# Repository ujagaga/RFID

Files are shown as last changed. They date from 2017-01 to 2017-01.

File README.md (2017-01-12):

RFID reader project for AtTiny2313 using MIFARE RFID-RC522 spi module

The RFID library is based on Addicore arduino library. I re-wrote it as pure C library and removed 
everything not esential to bare reading of an RFID TAG id to reduce the code size.

The initial commit contains a basic example of reading a tag and outputting the 4 bytes of id to UART.
The latest commit contains:
- full RFID example which can record up to 32 tag ids and unlock an electromagnetic lock
- EEPROM reader device which can be used to record the RFID readers memory and write it back on command
so that re-distributing codes between multiple locks can be simpified
- Linux and Windows console applications for administrating tag ids using either the EEPROM copy device 
or the RFID reader directly.

more details will be in the doc folder.

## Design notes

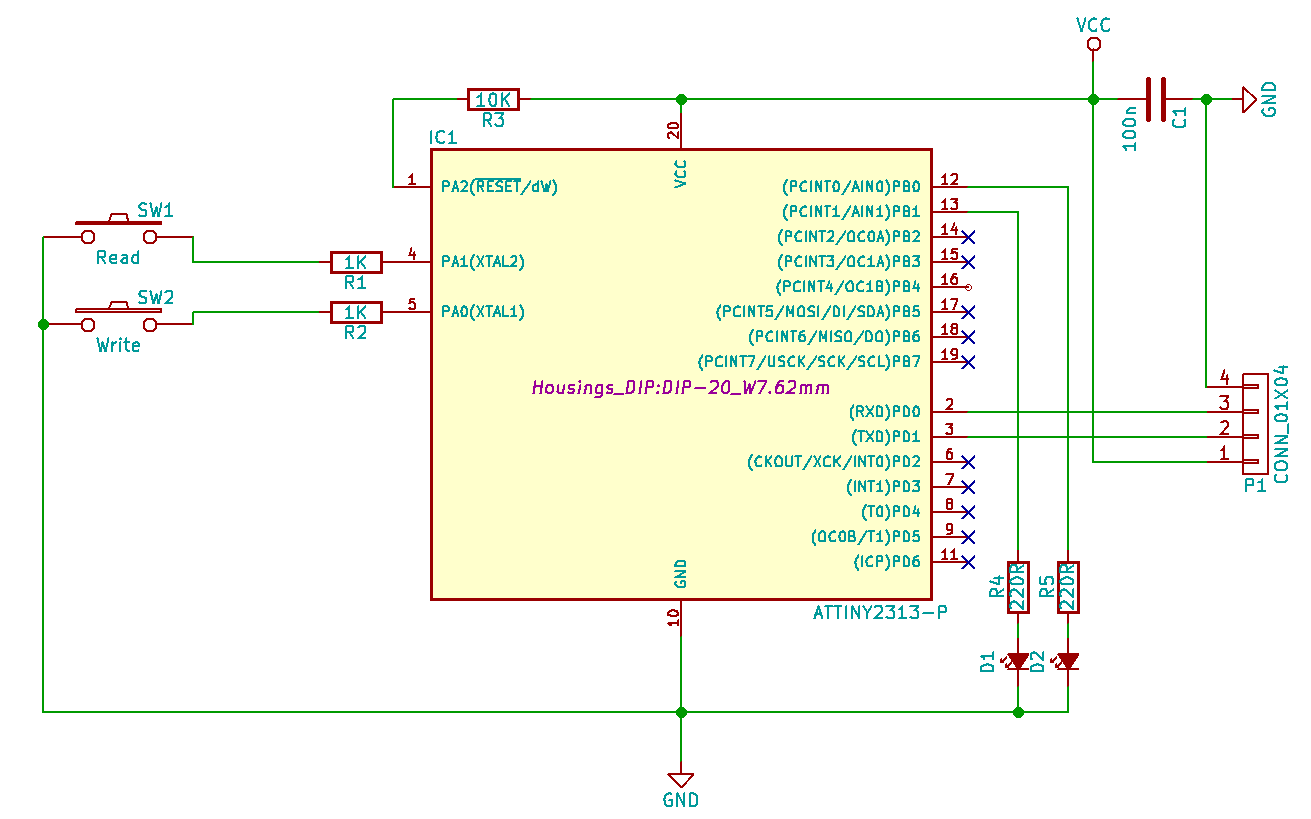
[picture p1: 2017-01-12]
doc/EEPROM_copy_device_schematic.png

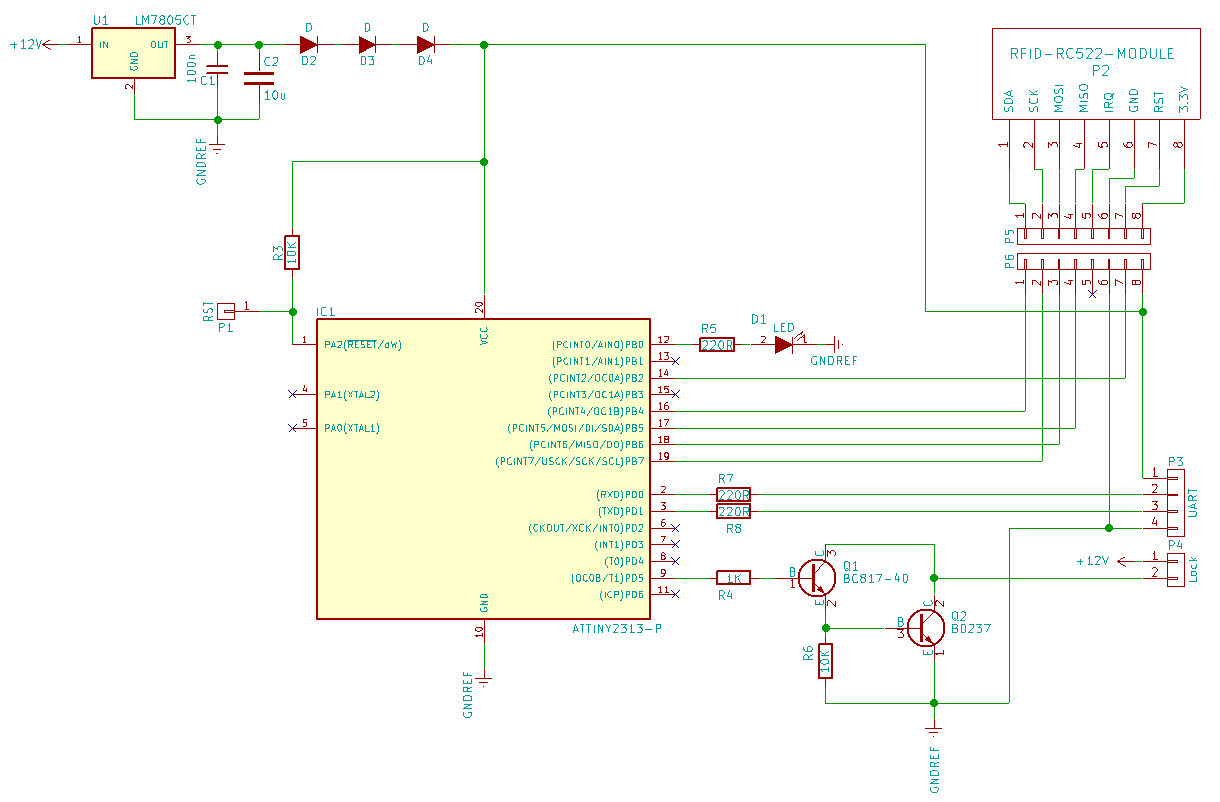
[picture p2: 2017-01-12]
doc/Reader_schematic.png

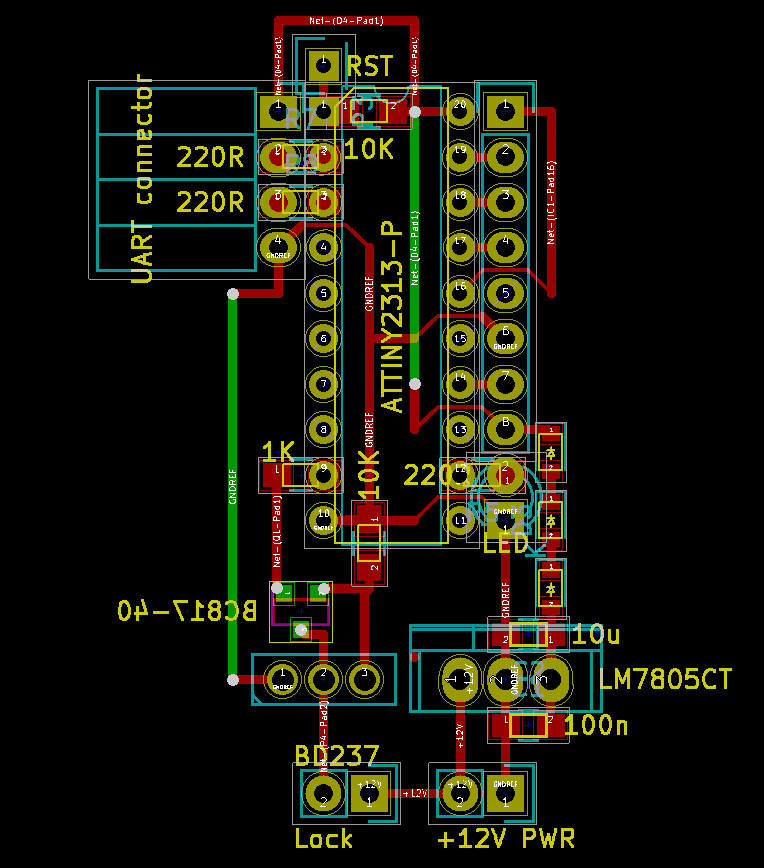
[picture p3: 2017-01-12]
Hardware/Reader_PCB.png

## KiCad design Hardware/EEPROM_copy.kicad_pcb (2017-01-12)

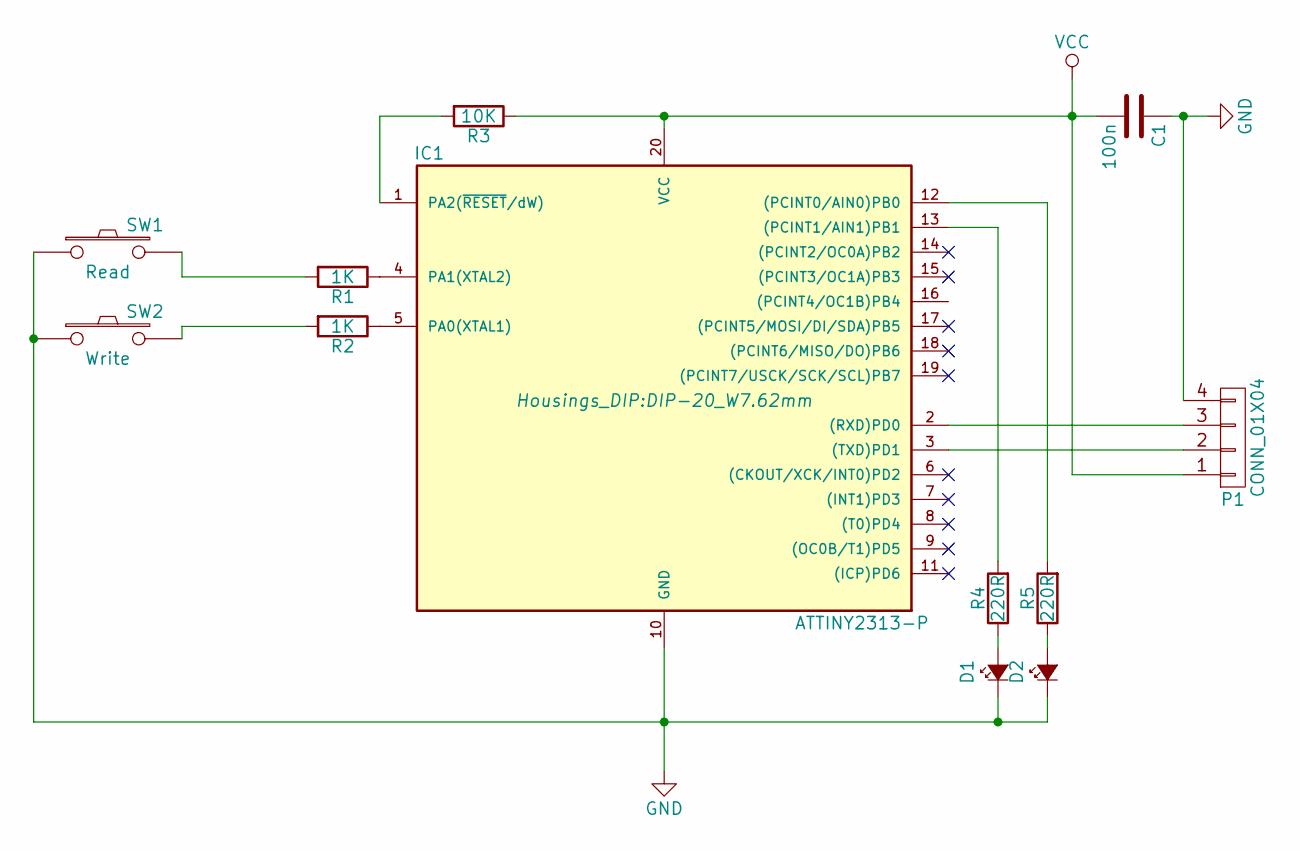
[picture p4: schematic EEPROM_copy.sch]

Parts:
C1: 100n; C_0805_HandSoldering
D1, D2: Led_Small; LED-3MM
IC1: ATTINY2313-P; DIP-20_W7.62mm
P1: CONN_01X04; Socket_Strip_Angled_1x04
R1, R2: 1K; R_0805
R3: 10K; R_0805
R4, R5: 220R; R_0805
SW1: Read; Micro_sw_1
SW2: Write; Micro_sw_1

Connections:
GND: C1.1, D1.1 (K), D2.1 (K), IC1.10 (GND), P1.4, SW1.1, SW2.1
unnamed: D1.2 (A), R4.1
unnamed: D2.2 (A), R5.1
unnamed: IC1.1 (PA2(~RESET~/dW)), R3.2
unnamed: IC1.2 ((RXD)PD0), P1.3
unnamed: IC1.3 ((TXD)PD1), P1.2
unnamed: IC1.4 (PA1(XTAL2)), R1.1
unnamed: IC1.5 (PA0(XTAL1)), R2.1
unnamed: IC1.12 ((PCINT0/AIN0)PB0), R5.2
unnamed: IC1.13 ((PCINT1/AIN1)PB1), R4.2
unnamed: R1.2, SW1.2
unnamed: R2.2, SW2.2
VCC: C1.2, IC1.20 (VCC), P1.1, R3.1

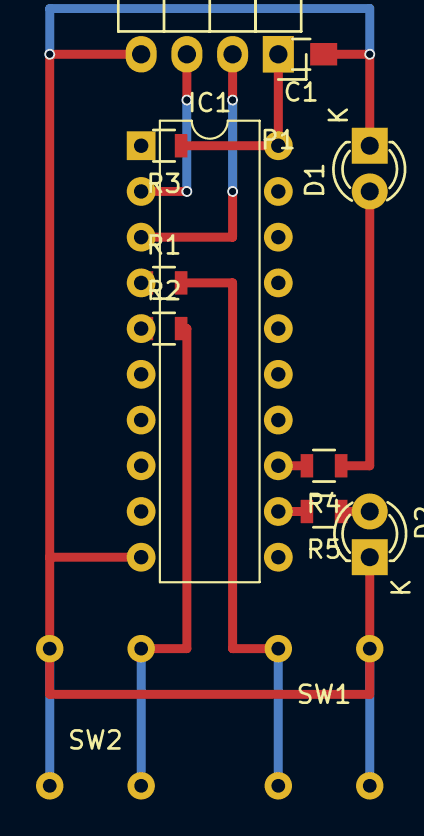
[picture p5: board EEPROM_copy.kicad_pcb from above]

Board: 2 copper layers, 12 parts (0 on the bottom side), 13 nets.

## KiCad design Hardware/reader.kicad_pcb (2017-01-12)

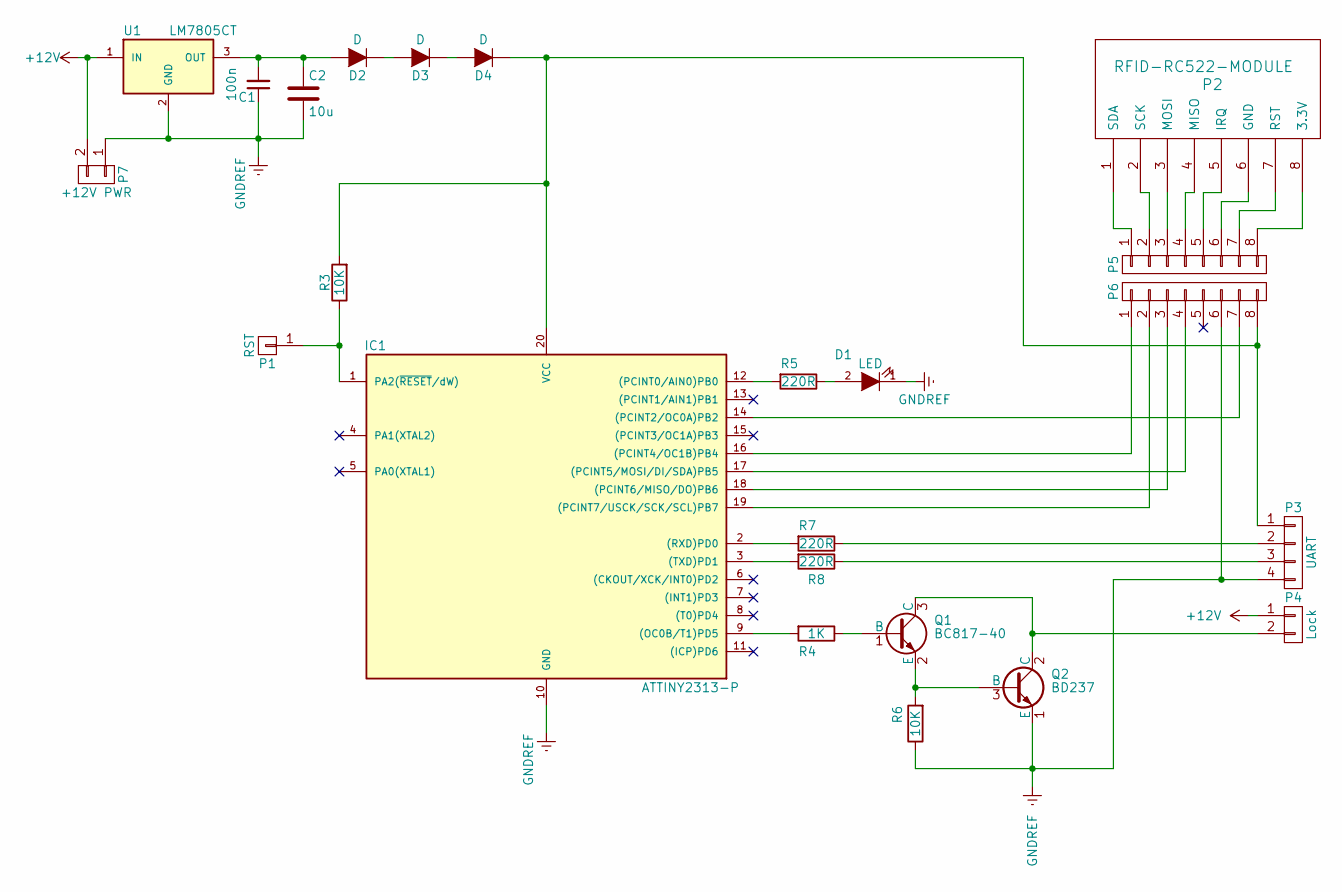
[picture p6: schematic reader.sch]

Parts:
C1: 100n; C_0805_HandSoldering
C2: 10u; C_0805_HandSoldering
D1: LED; LED-3MM
D2, D3, D4: D; D_0805
IC1: ATTINY2313-P; DIP-20_W7.62mm
P1: RST; Socket_Strip_Straight_1x01
P2: RFID-RC522-MODULE; Socket_Strip_Straight_1x08
P3: UART; Socket_Strip_Angled_1x04
P4: Lock; Socket_Strip_Straight_1x02
P5, P6: CONN_01X08; Socket_Strip_Straight_1x08
P7: +12V PWR; Socket_Strip_Straight_1x02
Q1: BC817-40; SOT-23
Q2: BD237; SOT126_SOT32_Housing_Vertical
R3, R6: 10K; R_0805_HandSoldering
R4: 1K; R_0805_HandSoldering
R5, R7, R8: 220R; R_0805_HandSoldering
U1: LM7805CT; TO-220

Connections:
+12V: P4.1, P7.2, U1.1 (IN)
GNDREF: C1.1, C2.2, D1.1 (K), IC1.10 (GND), P3.4, P6.6, P7.1, Q2.1 (E), R6.1, U1.2 (GND)
unnamed: C1.2, C2.1, D2.2 (A), U1.3 (OUT)
unnamed: D1.2 (A), R5.1
unnamed: D2.1 (K), D3.2 (A)
unnamed: D3.1 (K), D4.2 (A)
unnamed: D4.1 (K), IC1.20 (VCC), P3.1, P6.8, R3.2
unnamed: IC1.1 (PA2(~RESET~/dW)), P1.1, R3.1
unnamed: IC1.2 ((RXD)PD0), R7.2
unnamed: IC1.3 ((TXD)PD1), R8.2
unnamed: IC1.9 ((OC0B/T1)PD5), R4.2
unnamed: IC1.12 ((PCINT0/AIN0)PB0), R5.2
unnamed: IC1.14 ((PCINT2/OC0A)PB2), P6.7
unnamed: IC1.16 ((PCINT4/OC1B)PB4), P6.1
unnamed: IC1.17 ((PCINT5/MOSI/DI/SDA)PB5), P6.4
unnamed: IC1.18 ((PCINT6/MISO/DO)PB6), P6.3
unnamed: IC1.19 ((PCINT7/USCK/SCK/SCL)PB7), P6.2
unnamed: P2.1 (SDA), P5.1
unnamed: P2.2 (SCK), P5.2
unnamed: P2.3 (MOSI), P5.3
unnamed: P2.4 (MISO), P5.4
unnamed: P2.5 (IRQ), P5.5
unnamed: P2.6 (GND), P5.6
unnamed: P2.7 (RST), P5.7
unnamed: P2.8 (3.3V), P5.8
unnamed: P3.2, R7.1
unnamed: P3.3, R8.1
unnamed: P4.2, Q1.3 (C), Q2.2 (C)
unnamed: Q1.1 (B), R4.1
unnamed: Q1.2 (E), Q2.3 (B), R6.2

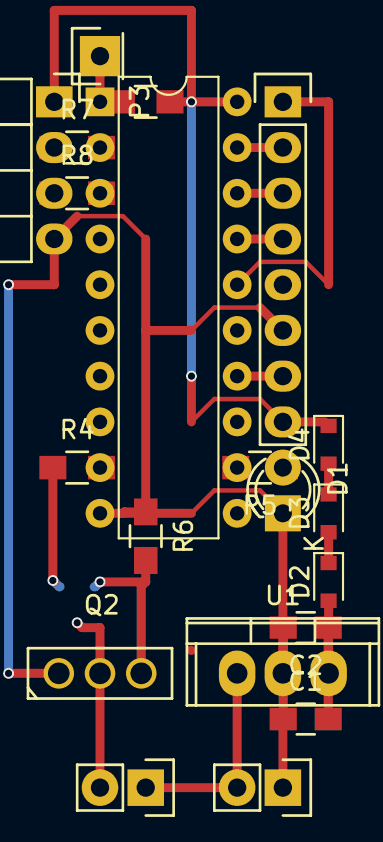
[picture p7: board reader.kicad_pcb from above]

Board: 2 copper layers, 21 parts (1 on the bottom side), 22 nets.

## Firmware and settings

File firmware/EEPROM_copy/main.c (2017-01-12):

#include "main.h"
#include "uart.h"

#define LED_grnOn()			do{PORTB |= (1 << LED_GRN_PIN);}while(0)
#define LED_grnOff()		do{PORTB &= ~(1 << LED_GRN_PIN);}while(0)
#define LED_redOn()			do{PORTB |= (1 << LED_RED_PIN);}while(0)
#define LED_redOff()		do{PORTB &= ~(1 << LED_RED_PIN);}while(0)
#define BtnReadPressed()	((PINA & (1 << BTN_READ_PIN)) == 0)
#define BtnWritePressed()	((PINA & (1 << BTN_WRITE_PIN)) == 0)

#define MAX_TAG_COUNT	(32)
uint32_t EEMEM savedIds[MAX_TAG_COUNT];


void setup() {

	/* set LED pins as output */
	DDRB = (1 << LED_RED_PIN) | (1 << LED_GRN_PIN);

	DDRA = 0;

	/* activate pushbutton pins pull-up resistors */
	PORTA = (1 << BTN_READ_PIN) | (1 << BTN_WRITE_PIN);

	/* Uart init */
	DDRD |= (1 << PD1);
	UBRRL = (unsigned char)BAUD_PRESCALE;
	UBRRH = (BAUD_PRESCALE >> 8);
	UCSRB = (1<<TXEN) | (1<<RXEN) | (1 << RXCIE);

	sei();

	wrIdx = 0;
	rdIdx = 0;
}

/* Reads RFID readers saved tags.
 * if verifyOnly flag is set, then it compares with EEPROM content without writing.
 * */
bool readRfidMem( bool verifyOnly ){
	uint8_t command = 'r', response;
	uint8_t i;
	uint32_t tagId;

	/* clear queue in case of garbage due to previous unsuccessful operation */
	uart_queueClear();

	/* Send read command */
	uart_print(&command, 1);

	response = 0;
	/* wait for response */
	if(!uart_readMsg(&response, 1)){
		/* communication failed */
		return false;
	}

	if(response != 'r'){
		uart_print(&response, 1);
		return false;
	}

	response = 1;
	/* wait for data for 32 tags and write them to EEPROM */
	for(i = 0; i < MAX_TAG_COUNT; i++){

		if(!uart_readMsg((uint8_t*)&tagId, 4)){
			/* communication failed */
			return false;
		}

		if(verifyOnly){
			/* verify written tags */
			uint32_t storedId = eeprom_read_dword(&savedIds[i]);
			if(storedId != tagId){
				return false;
			}
		}else{
			eeprom_update_dword(&savedIds[i], tagId);
		}

		/* Send acknowledge response  */
		uart_print(&response, 1);
	}

	return true;

}

bool writeRfidMem( void ){
	uint8_t command = 'w', response;
	uint8_t i;
	uint32_t tagId;

	/* clear queue in case of garbage due to previous unsuccessful operation */
	uart_queueClear();

	uart_print(&command, 1);

	/* wait for response */
	if(!uart_readMsg(&response, 1)){
		/* communication failed */
		return false;
	}

	if(response != 'w'){
		return false;
	}

	/* send data */
	for(i = 0; i < MAX_TAG_COUNT; i++){
		tagId = eeprom_read_dword(&savedIds[i]);

		uart_print((uint8_t*)&tagId, 4);

		/* wait for acknowledge */
		if(!uart_readMsg(&response, 1)){
			/* communication failed */
			return false;
		}

		if(response != 1){
			/* Bad response */
			return false;
		}
	}

	return true;

}

int main( void )
{
	setup();

	/* Just a signal to the user that
	 * everything is ready and power is on*/
	LED_grnOn();
	_delay_ms(300);
	LED_redOn();
	_delay_ms(300);
	LED_grnOff();
	_delay_ms(300);
	LED_redOff();


	while(1){

		if(BtnReadPressed() || BtnWritePressed()){
			_delay_ms(100);	/* de-bounce */

			if(BtnReadPressed()){

				LED_grnOn();
				LED_redOn();

				/* wait for the user to release both pushbuttons to prevent repeated operation*/
				while(BtnReadPressed());

				if(readRfidMem(false) && readRfidMem(true)){
					LED_redOff();
					LED_grnOn();
				}else{
					LED_grnOff();
					LED_redOn();
				}
			}else if(BtnWritePressed()){

				LED_grnOn();
				LED_redOn();

				/* wait for the user to release both pushbuttons to prevent repeated operation*/
				while(BtnWritePressed());

				if(writeRfidMem() && readRfidMem(true)){
					LED_redOff();
				}else{
					LED_grnOff();
				}
			}

			_delay_ms(1000);
		}
	}
}

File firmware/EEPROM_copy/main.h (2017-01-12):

#ifndef MAIN_H
#define MAIN_H

#include <stdint.h>
#include <avr/io.h>
#include <avr/interrupt.h>
#include <stdint.h>
#include <stdbool.h>
#include <util/delay.h>
#include <avr/eeprom.h>


#define LED_GRN_PIN		PB0
#define LED_RED_PIN 	PB1
#define BTN_READ_PIN	PA0
#define BTN_WRITE_PIN	PA1

#endif

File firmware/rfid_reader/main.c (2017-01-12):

#include "main.h"
#include "RFID.h"
#include "spi.h"
#include "uart.h"
#include <string.h>


//Maximum length of the array
#define MAX_TAG_COUNT	(32)

#define DoorUnlock()	do{ PORTD |= (1 << DOOR_PIN); }while(0)
#define DoorLock()		do{ PORTD &= ~(1 << DOOR_PIN); }while(0)
#define LED_on()		do{ PORTB |= (1 << LED_PIN); }while(0)
#define LED_off()		do{ PORTB &= ~(1 << LED_PIN); }while(0)
#define LED_tgl()		do{ PORTB ^= (1 << LED_PIN); }while(0)

typedef enum{
	start,
	waitMasterId,
	program,
	normal
}state_t;

uint32_t EEMEM savedIds[MAX_TAG_COUNT];
uint32_t masterId;

void setup() {
	// Configure port directions.
	// Set the chipSelectPin as digital output, do not select the slave yet
	// Set the resetPowerDownPin as digital output, do not reset or power down.
	DIR_REG = (1<<USI_DATAOUT_PIN) | (1<<USI_CLOCK_PIN) | (1 << MFRC_CS) | (1 << MFRC_RESET);

	OUT_REG = (1<<USI_DATAIN_PIN)  // Pull-ups.
				| (1 << MFRC_CS);	// Slave release for now

	DDRB |= (1 << LED_PIN);
	// Configure USI to 3-wire master mode with overflow interrupt.

	USICR = (1<<USIOIE) | (1<<USIWM0) | (1<<USICS1) | (USICS0) | (1<<USICLK);

	/* Uart init */
	DDRD |= (1 << PD1) | (1 << DOOR_PIN);
	UBRRL = (unsigned char)BAUD_PRESCALE;
	UBRRH = (BAUD_PRESCALE >> 8);
	UCSRB = (1<<TXEN) | (1<<RXEN) | (1 << RXCIE);

	RFID_Init();

	sei();

	masterId = eeprom_read_dword(&savedIds[0]);

	LED_on();
	DoorLock();
	wrIdx = 0;
	rdIdx = 0;

	_delay_ms(100);
}

/* Delays with the LED blinking.
 * Duration is in units of 100ms
 */
void LED_delay(uint8_t duration)
{
	uint8_t i;

	for(i = 0; i<duration; i++){
		LED_tgl();
		_delay_ms(100);
	}
}


/* Reads an RFID tag if present
 * returns 0 if none is present, 32-bit ID if one is read
 */
uint32_t readTagId( void )
{
	uint8_t calcChecksum;
	uint8_t status;
	uint8_t str[RFID_MSG_MAX_LEN];


	str[0] = 0;
	str[1] = 0x44;
	//Find tags, return tag type
	status = RFID_Request(str);
	//Anti-collision, return tag serial number 4 bytes
	status = RFID_Anticoll(str);

	calcChecksum = str[0] ^ str[1] ^ str[2] ^ str[3];

	uint32_t* cardId = (uint32_t*)str;

	if ((status != MI_OK) || (calcChecksum != str[4]))
	{
		*cardId = 0;
	}

	return *cardId;
}


/*
 * Checks if a tag is already saved.
 * returns true if found in EEPROM, false otherwise
 * If "add" is set, and it is not found, it will be saved
 */
bool checkTag(uint32_t ID, bool add)
{
	uint8_t i = 0;
	uint32_t temp;
	uint8_t emptySpot = 0;

	for(i = 0; i < MAX_TAG_COUNT; i++){
		temp = eeprom_read_dword(&savedIds[i]);

		if(temp == ID){
			/* Already saved */
			return true;

		}else if((temp == 0xFFFFFFFF) || (temp == 0)){
			/* found empty space, so remember this location */
			if(emptySpot == 0){
				emptySpot = i;
			}
		}
	}

	if(add){
		/* The tag was not found but should be saved */
		if(emptySpot != 0){
			/* An empty spot was found */
			eeprom_update_dword(&savedIds[emptySpot], ID);
		}/* else no more space to save a new tag */
	}

	return false;
}


void processMsg( void )
{
	uint8_t command, response;

	uart_readMsg(&command, 1);

	if(command == 'r'){
		/* respond to detected command */
		uart_print(&command, 1);

		/* start transmitting tags */
		uint8_t i;

		for(i = 0; i < MAX_TAG_COUNT; i ++){

			uint32_t tagId = eeprom_read_dword(&savedIds[i]);

			uart_print((uint8_t*)&tagId, 4);

			if(!uart_readMsg(&response, 1)){
				/* No response, so communication failed */
				break;
			}

			if(response != 1){
				/* Bad response */
				break;
			}
		}
	}else if(command == 'w'){
		/* respond to detected command */
		uart_print(&command, 1);

		/* start writing tags */
		uint8_t i;
		uint32_t msgBuffer;

		response = 1;
		for(i = 0; i < MAX_TAG_COUNT; i++){

			if(!uart_readMsg((uint8_t*)&msgBuffer, 4)){
				/* communication failed and tag id-s are not OK*/
				uart_queueClear();
				return;
			}

			eeprom_update_dword(&savedIds[i], msgBuffer);
			/* send acknowledge to confirm writing */
			uart_print(&response, 1);
		}
	}else{
		command = 0;
		uart_print(&command, 1);
		uart_queueClear();
	}
}


int main( void )
{
	uint32_t tagId;
	state_t state = start;

	setup();

	while(1){

		tagId = readTagId();

		switch(state){
			case start:
			{
				if(masterId == 0xFFFFFFFF){
					/* Not set */
					state = waitMasterId;
				}else{
					state = normal;
				}
				break;
			}

			case waitMasterId:
			{
				LED_tgl();
				if(tagId != 0){
					masterId = tagId;
					eeprom_update_dword(&savedIds[0], tagId);
					state = normal;
					LED_delay(30);	/* delay for 3 seconds so you have time to remove the master tag */
				}
				break;
			}

			case program:
			{
				LED_tgl();
				if(tagId != 0){
					checkTag(tagId, true);
					state = normal;
					LED_delay(30);
				}
				break;
			}


			default:
			{	/* normal state */
				LED_on();

				if(tagId != 0){
					if(tagId == masterId){
						state = program;
					}else if(checkTag(tagId, false)){
						DoorUnlock();
						LED_delay(50);	/* keep door unlocked for 5 seconds */
						DoorLock();
					}
				}

				if(uart_queueHasMsg()){
					processMsg();
				}

				break;
			}
		}

		_delay_ms(300);
	}
}

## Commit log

2017-01-12 RFID reader basic HW and FW
    [reader.kicad_pcb, reader.sch]
2017-01-12 * EEPROM copy device HW and FW * administration python scripts for EEPROM reader and RFID reader * Python scripts bundled into standalone apps for both Linux and Win
    [EEPROM_copy.kicad_pcb, EEPROM_copy.sch, reader.kicad_pcb]
